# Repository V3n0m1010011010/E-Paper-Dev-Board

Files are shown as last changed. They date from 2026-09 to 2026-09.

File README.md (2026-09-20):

# ESP32 E-Paper Board

Eine kompakte, selbst entwickelte ESP32-S3-Platine für portable Anwendungen mit E-Paper-Display, microSD-Karte, Navigationstaster und LiPo-Akku.

## Features

- ESP32-S3-WROOM-1U
- 1.54" E-Paper Display
- microSD-Karten-Slot
- 3-Wege-Navigationstaster
  - UP
  - DOWN
  - PUSH
- USB-C für Stromversorgung, Programmierung und serielle Kommunikation
- 3.7 V LiPo-Akku
- Integrierter LiPo-Ladecontroller
- 3.3 V Spannungsversorgung
- Kompakte Bauform

## 3D-Modell

### Oberseite

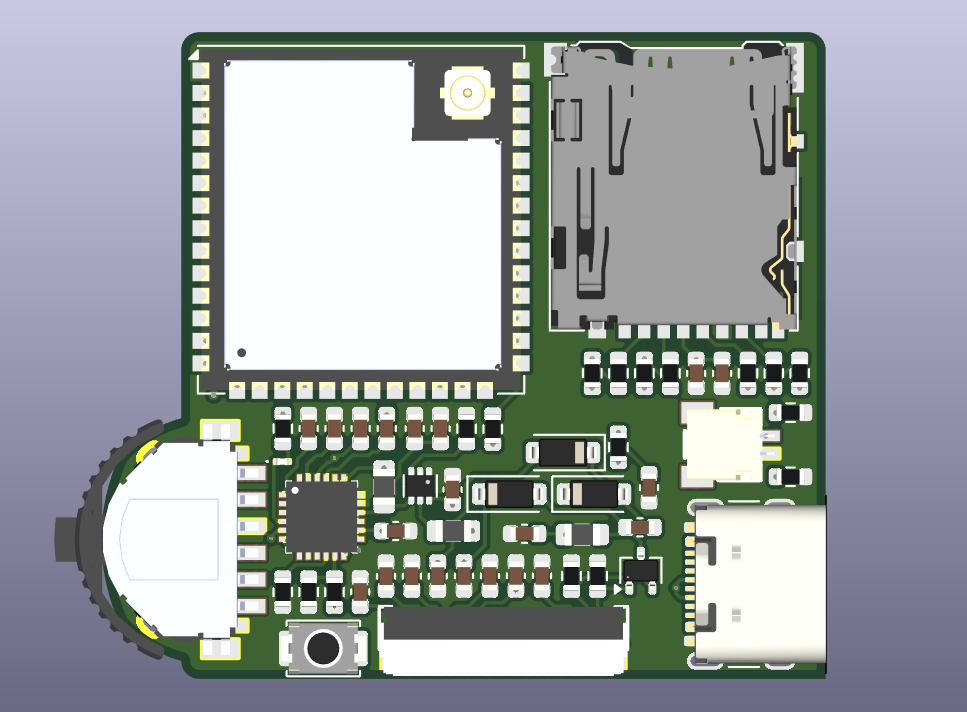
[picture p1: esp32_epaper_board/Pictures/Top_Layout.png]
Top Layout


### Unterseite

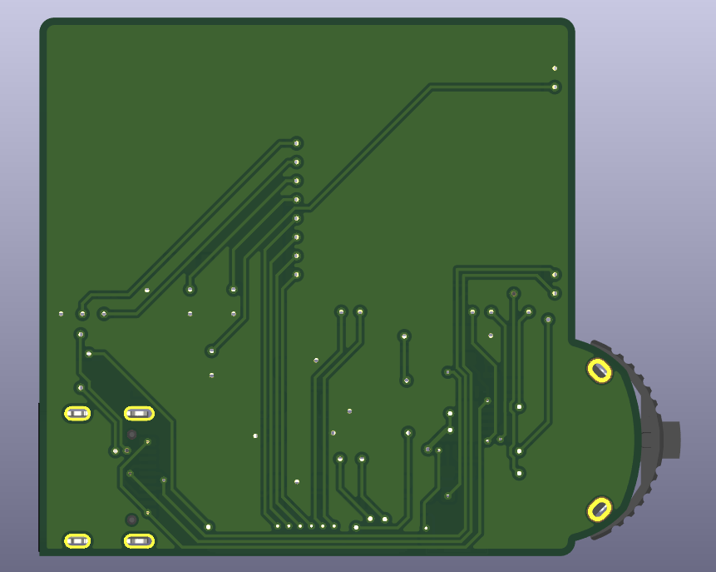
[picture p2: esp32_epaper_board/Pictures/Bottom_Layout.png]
Bottom Layout


## Verwendete Komponenten

| Komponente | Beschreibung |
|---|---|
| ESP32-S3-WROOM-1U | Hauptcontroller |
| GDEY0154D67 | 1.54" E-Paper Display |
| BQ25896 | LiPo-Ladecontroller |
| TPS62843 | 3.3 V Buck-Converter |
| TS43-135255-10-BK-200-SMT-TR | Navigationstaster |
| USB4105 | USB-C Anschluss |
| SM02B-SRSS-TB(LF)(SN) | JST-Akkuanschluss |

## Dokumentation

Die verwendeten Datenblätter befinden sich im Ordner [`Docs`](./esp32_epaper_board/Docs/).

Enthalten sind unter anderem die Datenblätter für:

- [ESP32-S3-WROOM-1U](./esp32_epaper_board/Docs/ESP32-S3-WROOM-1U-N8_Espressif_Systems.pdf)
- [GDEY0154D67 E-Paper Display](./esp32_epaper_board/Docs/GDEY0154D67-new.pdf)
- [BQ25896 LiPo-Ladecontroller](./esp32_epaper_board/Docs/bq25896.pdf)
- [TPS62843 Spannungsregler](./esp32_epaper_board/Docs/tps62843.pdf)
- [TS43-135255-10-BK-200-SMT-TR Navigationstaster](./esp32_epaper_board/Docs/TS43-135255-10-BK-200-SMT-TR_Same_Sky.pdf)
- [USB4105 USB-C Anschluss](./esp32_epaper_board/Docs/usb4105.pdf)
- [SM02B-SRSS JST Anschluss](./esp32_epaper_board/Docs/SM02B-SRSS-TB(LF)(SN)_JST_Sales.pdf)

Die übrigen Dateien im `Docs`-Ordner enthalten zusätzliche Datenblätter und Referenzinformationen für das PCB-Design.

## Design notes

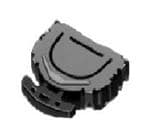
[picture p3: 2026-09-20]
esp32_epaper_board/Pictures/SLLB120300.jpg

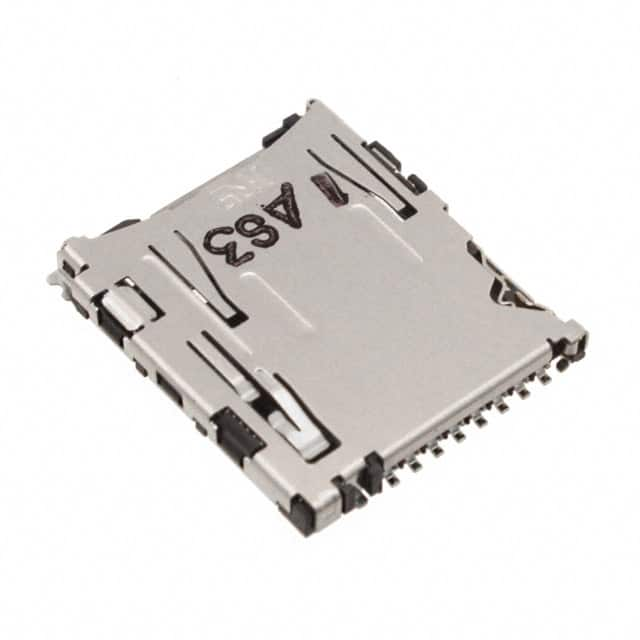
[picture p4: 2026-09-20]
esp32_epaper_board/Pictures/DM3ATSFPEJM5.jpg

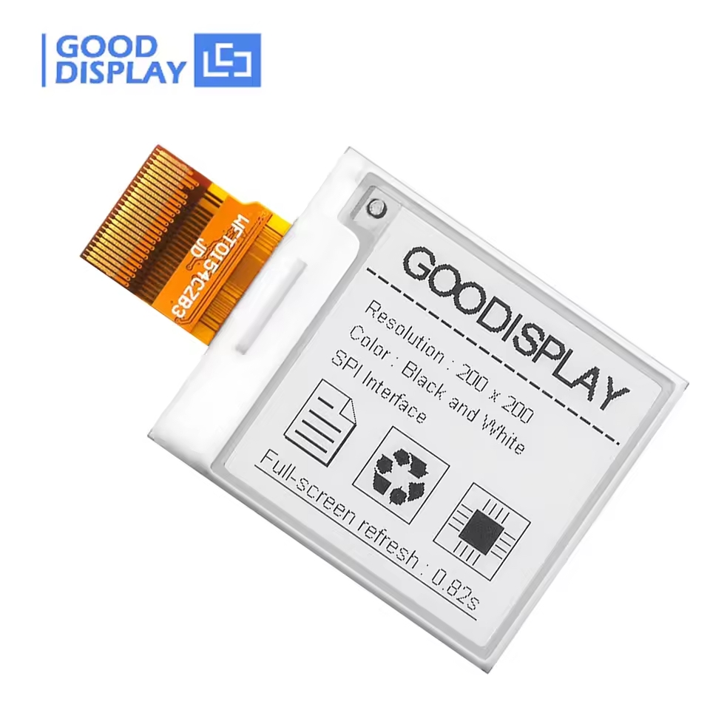
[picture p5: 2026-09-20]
esp32_epaper_board/Pictures/1_54epaper.jpg

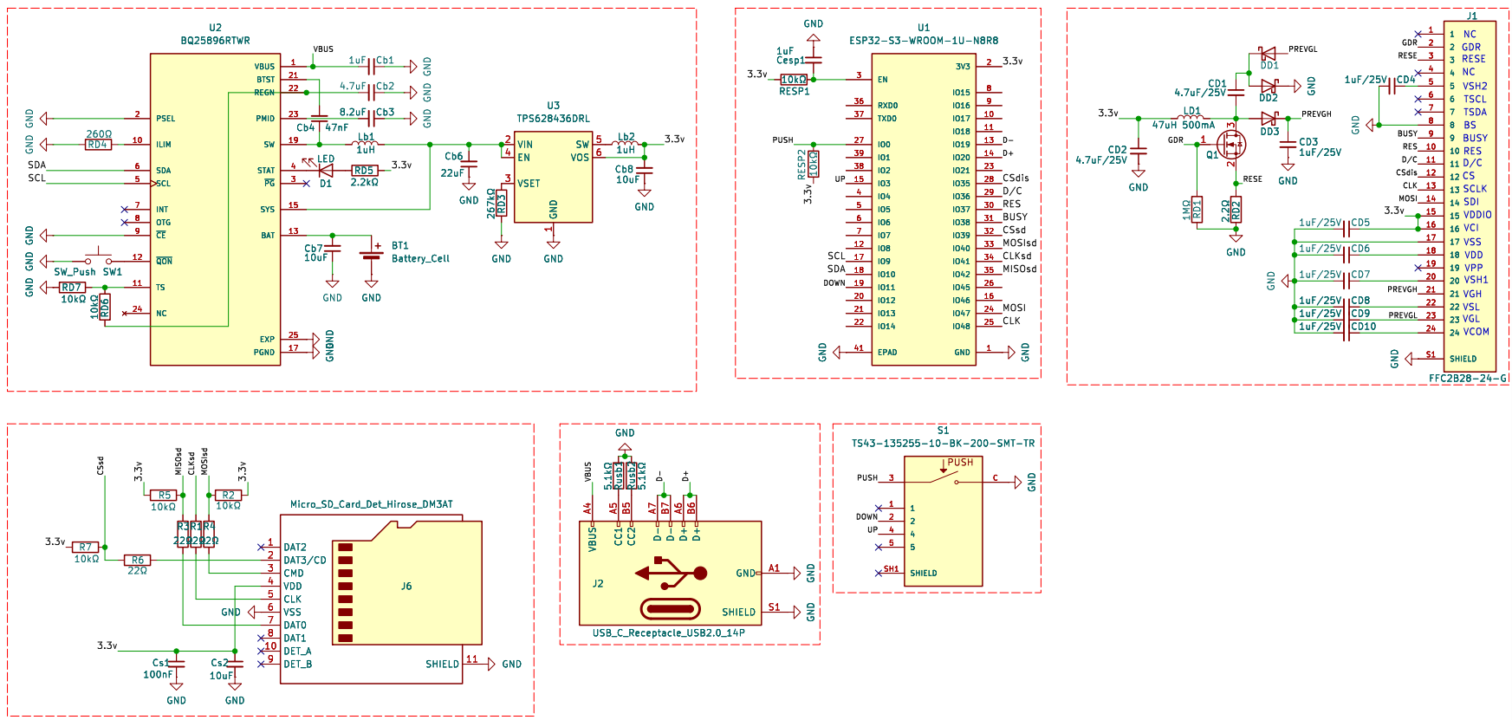
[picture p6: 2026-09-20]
esp32_epaper_board/Pictures/fullPlan.png

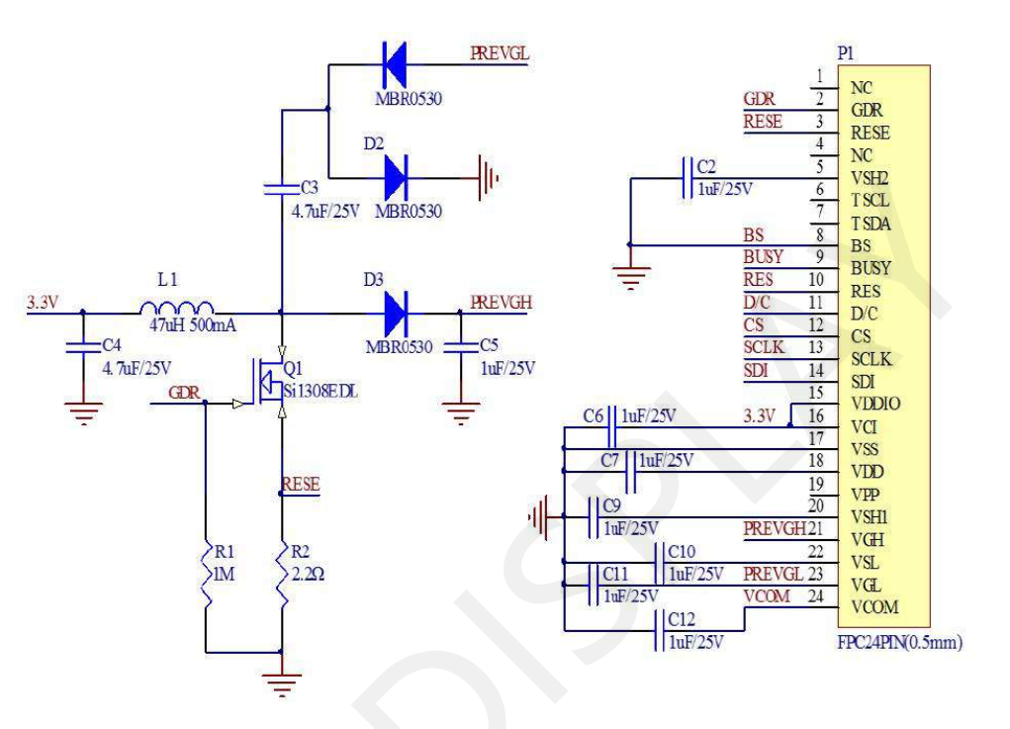
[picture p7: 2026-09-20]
esp32_epaper_board/Pictures/e-paper-schaltung.png

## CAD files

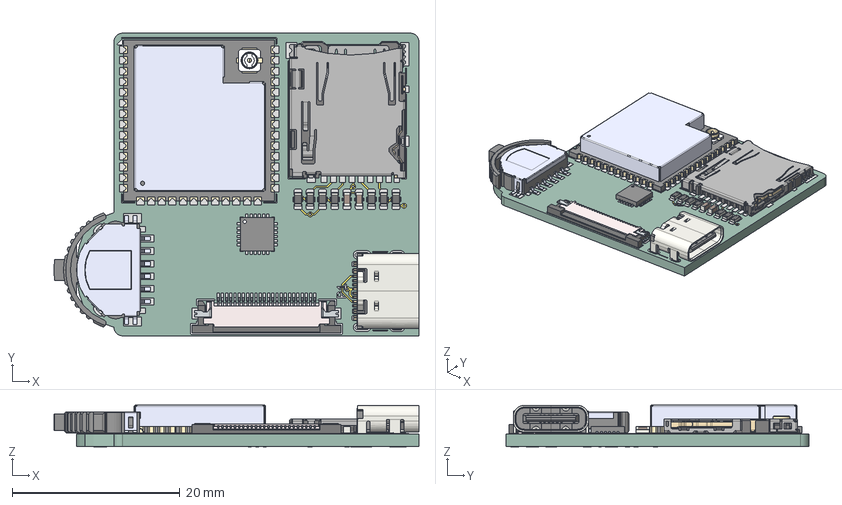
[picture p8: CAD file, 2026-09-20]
esp32_epaper_board/kicad/e-paper-esp32/e-paper-esp32.step
43.5 x 36.1 x 4.99 mm
ESP32-S3-WROOM-1U-N8R8--3DModel-STEP-56544
C_0603_1608Metric x 2
R_0603_1608Metric x 7
microSD_HC_Hirose_DM3AT-SF-PEJM5
TS43-135255-10-BK-200-SMT-TR
USB_C_Receptacle_GCT_USB4105-xx-A_16P_TopMnt_Horizontal
BQ25896RTWR
68x124183x22
68X1XX183X22_Pin_TOP x 24
68x124183x22_Actuator
68X1xx183x22_Solder_Pad2
68X1XX183X22_Solder_Pad
e-paper-esp32_copper
e-paper-esp32_pad
e-paper-esp32_via
e-paper-esp32_silkscreen
e-paper-esp32_PCB

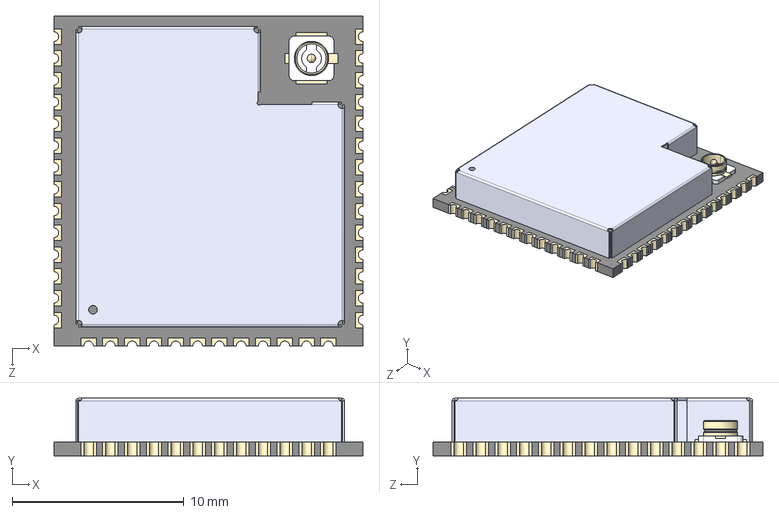
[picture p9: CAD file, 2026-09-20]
esp32_epaper_board/Module/ESP32-S3-WROOM-1U-N8R8/ESP32-S3-WROOM-1U-N8R8.step
18.0 x 3.35 x 19.2 mm

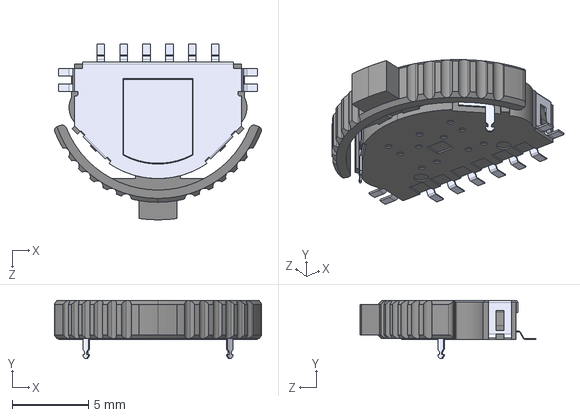
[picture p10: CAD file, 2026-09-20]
esp32_epaper_board/Module/TS43-135255-10-BK-200-SMT-TR/TS43-135255-10-BK-200-SMT-TR--3DModel-STEP-418109.STEP
13.5 x 3.80 x 11.5 mm

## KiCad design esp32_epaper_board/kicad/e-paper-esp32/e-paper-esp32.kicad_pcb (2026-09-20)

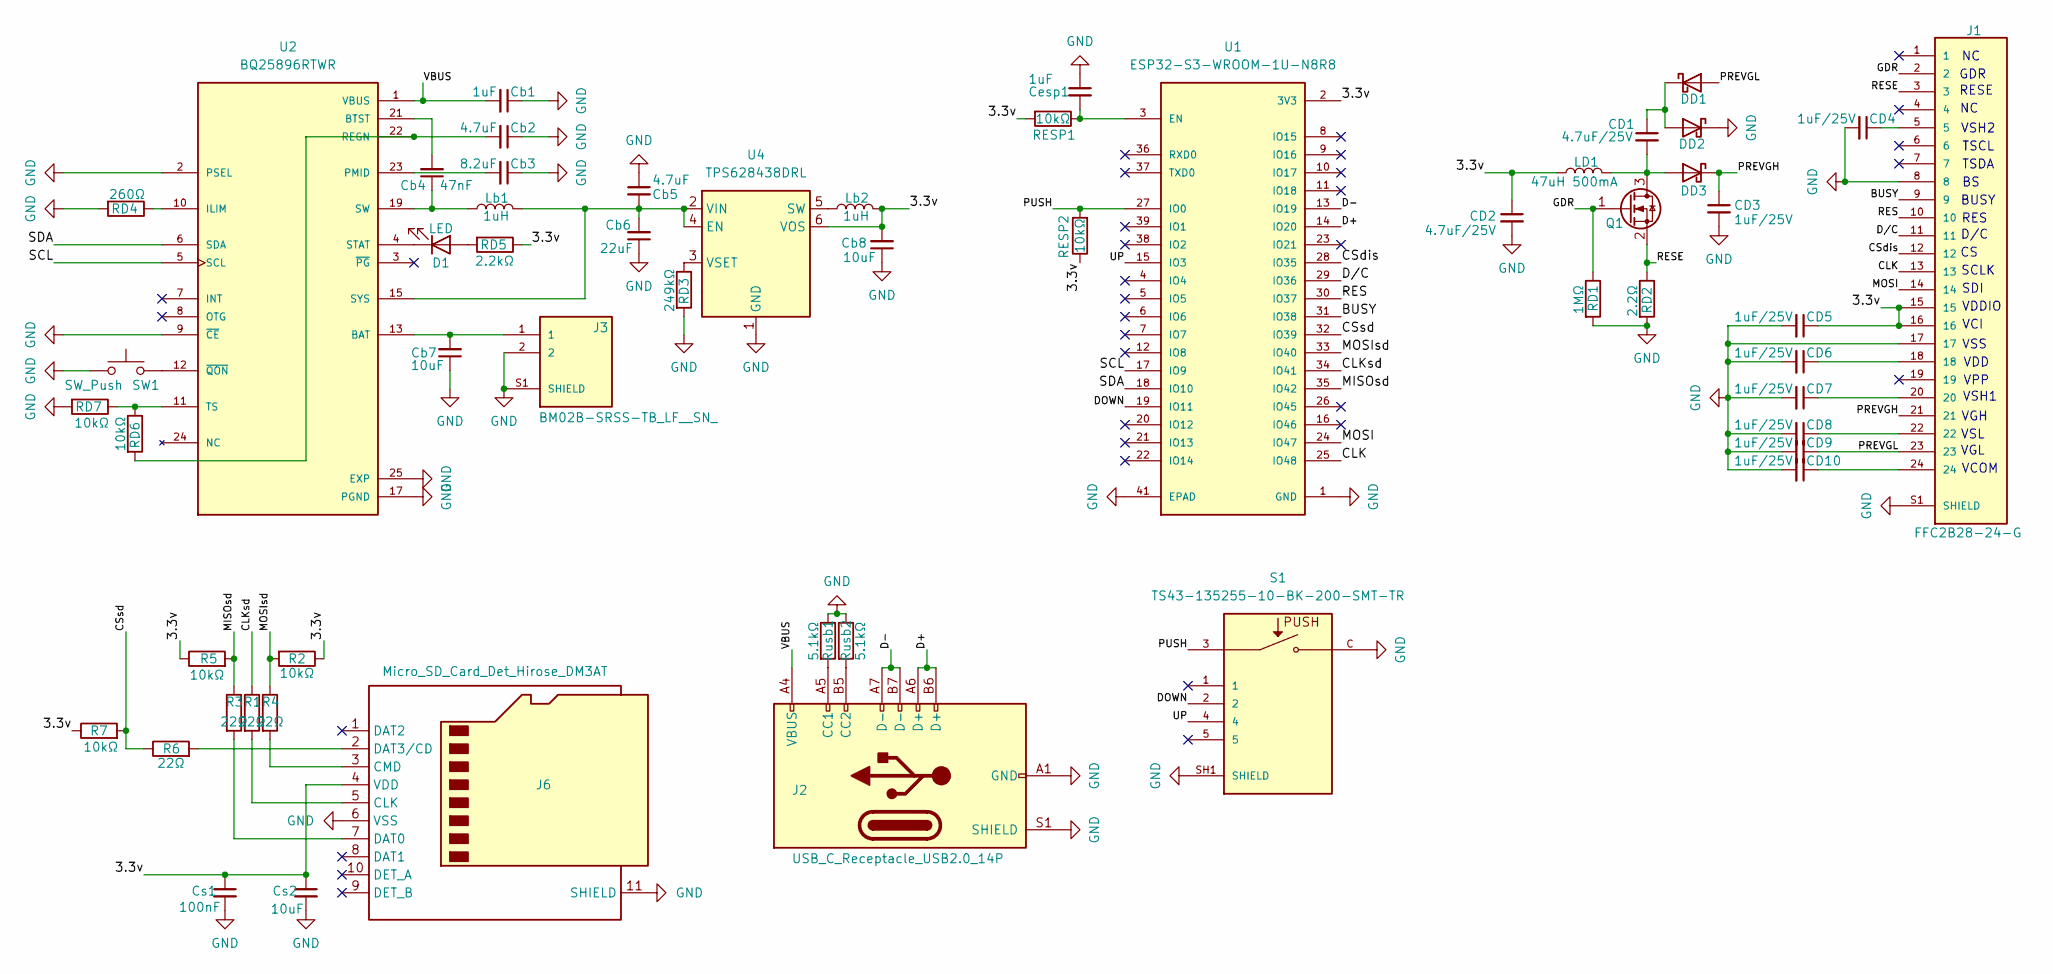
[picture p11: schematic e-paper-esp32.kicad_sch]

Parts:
CD1, CD2: 4.7uF/25V; C_0603_1608Metric
CD3, CD4, CD5, CD6, CD7, CD8, CD9, CD10: 1uF/25V; C_0603_1608Metric
Cb1: 1uF; C_0603_1608Metric
Cb2, Cb5: 4.7uF; C_0603_1608Metric
Cb3: 8.2uF; C_0603_1608Metric
Cb4: 47nF; C_0603_1608Metric
Cb6: 22uF; C_0603_1608Metric
Cb7, Cb8: 10uF; C_0603_1608Metric
Cesp1: 1uF; C_0603_1608Metric
Cs1: 100nF; C_0603_1608Metric
Cs2: 10uF; C_0603_1608Metric
D1: LED; LED_0201_0603Metric
DD1, DD2, DD3: MBR0530; D_SOD-123
J1: FFC2B28-24-G; GCT_FFC2B28-24-G; PARTREV A
J2: USB_C_Receptacle_USB2.0_14P; USB_C_Receptacle_GCT_USB4105-xx-A_16P_TopMnt_Horizontal
J3: BM02B-SRSS-TB_LF__SN_; SM02B-SRSS-TB_LF__SN; PARTREV N/A
J6: Micro_SD_Card_Det_Hirose_DM3AT; microSD_HC_Hirose_DM3AT-SF-PEJM5
LD1: 47uH 500mA; L_0805_2012Metric
Lb1, Lb2: 1uH; L_0805_2012Metric
Q1: Si1308EDL; SOT-323_SC-70
R1, R3, R4, R6: 22Ω; R_0603_1608Metric
R2, R5, R7: 10kΩ; R_0603_1608Metric
RD1: 1MΩ; R_0603_1608Metric
RD2: 2.2Ω; R_0603_1608Metric
RD3: 249kΩ; R_0603_1608Metric
RD4: 260Ω; R_0603_1608Metric
RD5: 2.2kΩ; R_0603_1608Metric
RD6, RD7: 10kΩ; R_0603_1608Metric
RESP1, RESP2: 10kΩ; R_0603_1608Metric
Rusb1, Rusb2: 5.1kΩ; R_0603_1608Metric
S1: TS43-135255-10-BK-200-SMT-TR; SW_TS43-135255-10-BK-200-SMT-TR
SW1: SW_Push; SW_Push_SPST_NO_Alps_SKRK
U1: ESP32-S3-WROOM-1U-N8R8; ESP32-S3-WROOM-1U; PARTREV v1.1
U2: BQ25896RTWR; IC_BQ25896RTWR; PARTREV C
U4: TPS628438DRL; SOT-563

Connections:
/3.3v: CD2.1, CD5.1, Cb8.2, Cs1.1, Cs2.1, J1.15, J1.16, J6.4 (VDD), LD1.2, Lb2.1, R2.1, R5.1, R7.1, RD5.1, RESP1.2, RESP2.1, U1.2 (3V3), U4.6 (VOS)
/BUSY: J1.9, U1.31 (IO38)
/CLK: J1.13, U1.25 (IO48)
/CLKsd: R1.1, U1.34 (IO41)
/CSdis: J1.12, U1.28 (IO35)
/CSsd: R6.1, R7.2, U1.32 (IO39)
/D+: J2.A6 (D+), J2.B6 (D+), U1.14 (IO20)
/D-: J2.A7 (D-), J2.B7 (D-), U1.13 (IO19)
/DOWN: S1.2, U1.19 (IO11)
/D/C: J1.11, U1.29 (IO36)
/GDR: J1.2, Q1.1 (G), RD1.1
/MISOsd: R3.1, R5.2, U1.35 (IO42)
/MOSI: J1.14, U1.24 (IO47)
/MOSIsd: R2.2, R4.1, U1.33 (IO40)
/PREVGH: CD3.1, DD3.1 (K), J1.21
/PREVGL: CD9.1, DD1.2 (A), J1.23
/PUSH: RESP2.2, S1.3, U1.27 (IO0)
/RES: J1.10, U1.30 (IO37)
/RESE: J1.3, Q1.2 (S), RD2.1
/SCL: U1.17 (IO9), U2.5 (SCL)
/SDA: U1.18 (IO10), U2.6 (SDA)
/UP: S1.4, U1.15 (IO3)
/VBUS: Cb1.2, J2.A4 (VBUS), J2.A9 (VBUS), J2.B4 (VBUS), J2.B9 (VBUS), U2.1 (VBUS)
GND: CD2.2, CD3.2, CD4.2, CD5.2, CD6.2, CD7.2, CD8.2, CD9.2, CD10.2, Cb1.1, Cb2.1, Cb3.1, Cb5.1, Cb6.1, Cb7.1, Cb8.1, Cesp1.1, Cs1.2, Cs2.2, DD2.1 (K), J1.8, J1.17, J1.S1 (SHIELD), J1.S2 (SHIELD), J2.A1 (GND), J2.A12 (GND), J2.B1 (GND), J2.B12 (GND), J2.S1 (SHIELD), J3.2, J3.S1 (SHIELD), J3.S2 (SHIELD), J6.6 (VSS), J6.11 (SHIELD), RD1.2, RD2.2, RD3.2, RD4.2, RD7.2, Rusb1.1, Rusb2.1, S1.C, S1.SH1 (SHIELD), S1.SH2 (SHIELD), S1.SH3 (SHIELD), S1.SH4 (SHIELD), S1.SH5 (SHIELD), S1.SH6 (SHIELD), SW1.1, U1.1 (GND), U1.40 (GND), U1.41 (EPAD), U1.41_1 (GND), U1.41_2 (GND), U1.41_3 (GND), U1.41_4 (GND), U1.41_5 (GND), U1.41_6 (GND), U1.41_7 (GND), U1.41_8 (GND), U1.41_9 (GND), U2.2 (PSEL), U2.9 (~CE), U2.17 (PGND), U2.18 (PGND), U2.25 (EXP), U4.1 (GND)
unnamed: CD4.1, J1.5
unnamed: CD6.1, J1.18
unnamed: CD7.1, J1.20
unnamed: CD8.1, J1.22
unnamed: CD10.1, J1.24
unnamed: Cb4.1, Lb1.2, U2.19 (SW), U2.20 (SW)
unnamed: Cb7.2, J3.1, U2.13 (BAT), U2.14 (BAT)
unnamed: D1.2 (A), RD5.2
unnamed: D1.1 (K), U2.4 (STAT)
unnamed: CD1.1, DD1.1 (K), DD2.2 (A)
unnamed: CD1.2, DD3.2 (A), LD1.1, Q1.3 (D)
unnamed: J2.A5 (CC1), Rusb1.2
unnamed: J2.B5 (CC2), Rusb2.2
unnamed: J6.5 (CLK), R1.2
unnamed: J6.3 (CMD), R4.2
unnamed: J6.7 (DAT0), R3.2
unnamed: J6.2 (DAT3/CD), R6.2
unnamed: Cesp1.2, RESP1.1, U1.3 (EN)
unnamed: Cb4.2, U2.21 (BTST)
unnamed: RD4.1, U2.10 (ILIM)
unnamed: Cb3.2, U2.23 (PMID)
unnamed: Cb2.2, RD6.2, U2.22 (REGN)
unnamed: RD6.1, RD7.1, U2.11 (TS)
unnamed: SW1.2, U2.12 (~QON)
unnamed: Cb5.2, Cb6.2, Lb1.1, U2.15 (SYS), U2.16 (SYS), U4.2 (VIN), U4.4 (EN)
unnamed: Lb2.2, U4.5 (SW)
unnamed: RD3.1, U4.3 (VSET)

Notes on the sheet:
BUSY
VGH
GDR
VSH2
VDD
SDI
VSH1
TSCL
RES
VSS
VCI
VCOM
SCLK
VPP
RESE
VGL
D/C
VDDIO
VSL
TSDA

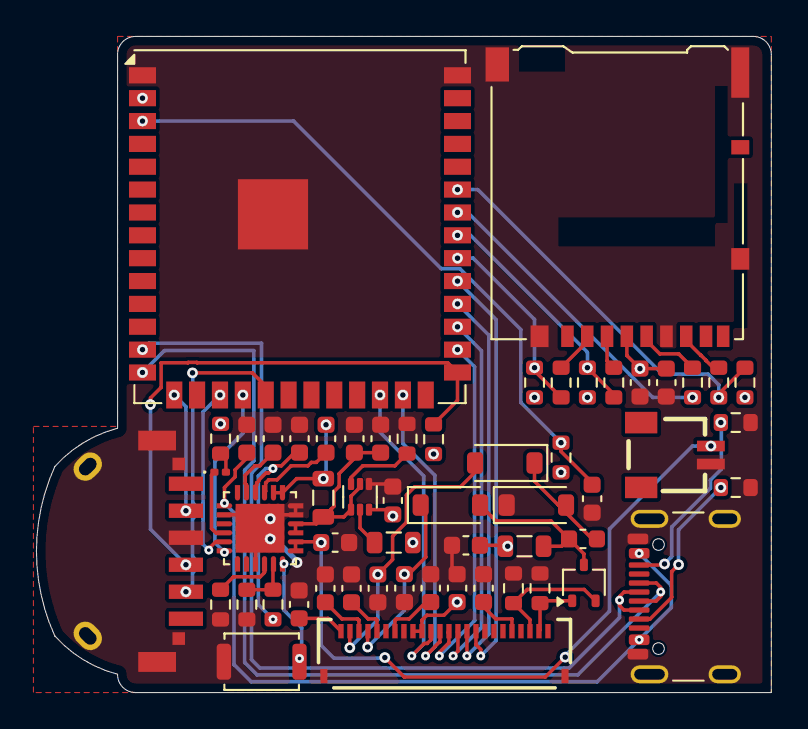
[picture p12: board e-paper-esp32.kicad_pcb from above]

Board: 2 copper layers, 40.8 x 36.4 mm, 56 parts (0 on the bottom side), 51 nets.

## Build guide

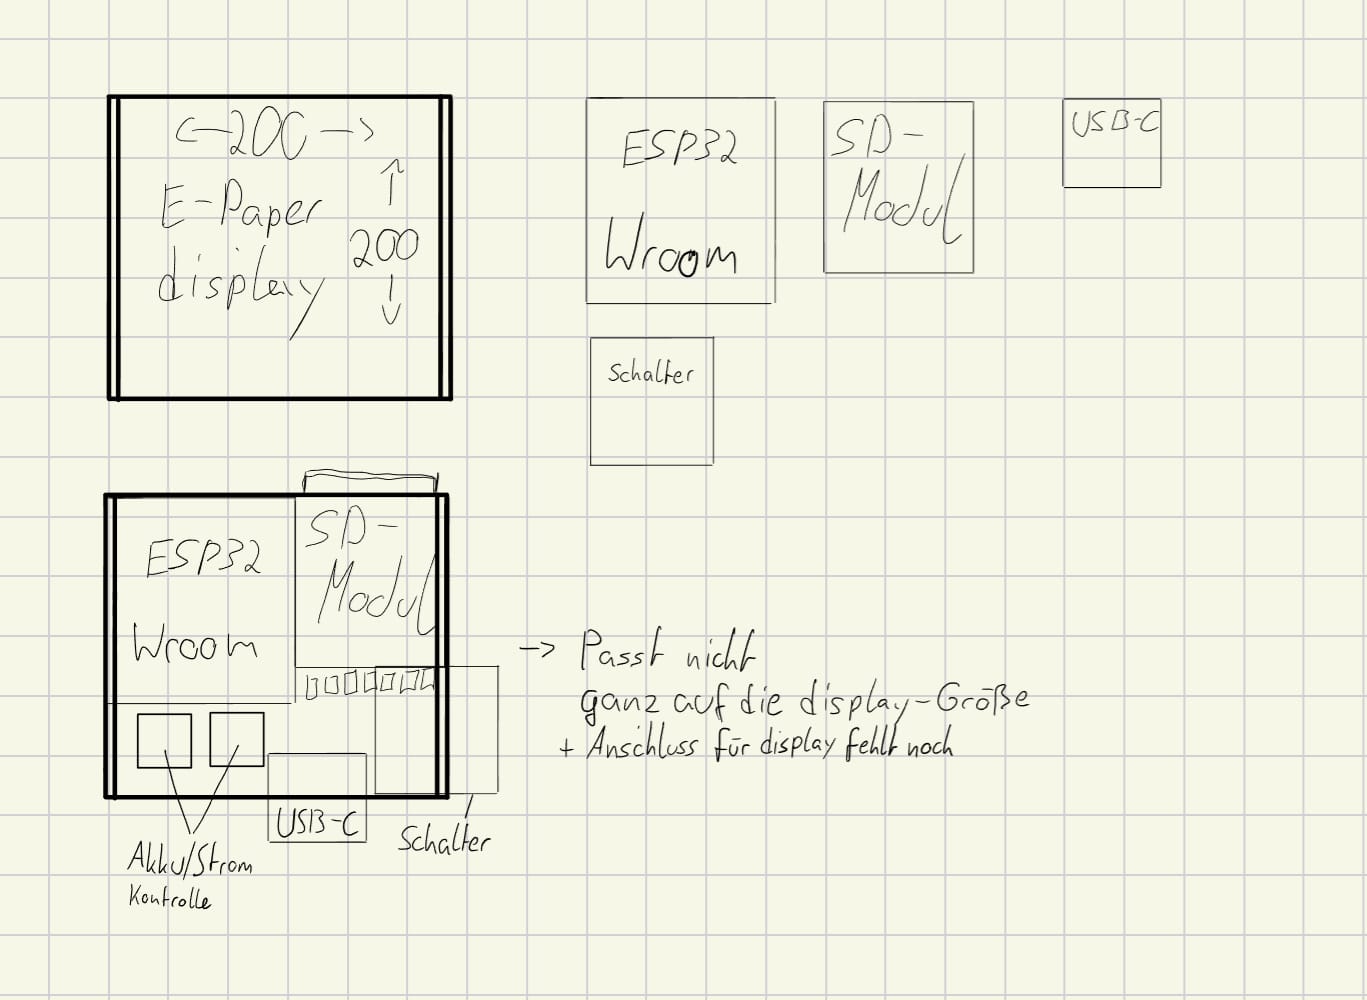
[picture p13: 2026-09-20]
esp32_epaper_board/Pictures/ersteSkizzeAufbau.jpeg
